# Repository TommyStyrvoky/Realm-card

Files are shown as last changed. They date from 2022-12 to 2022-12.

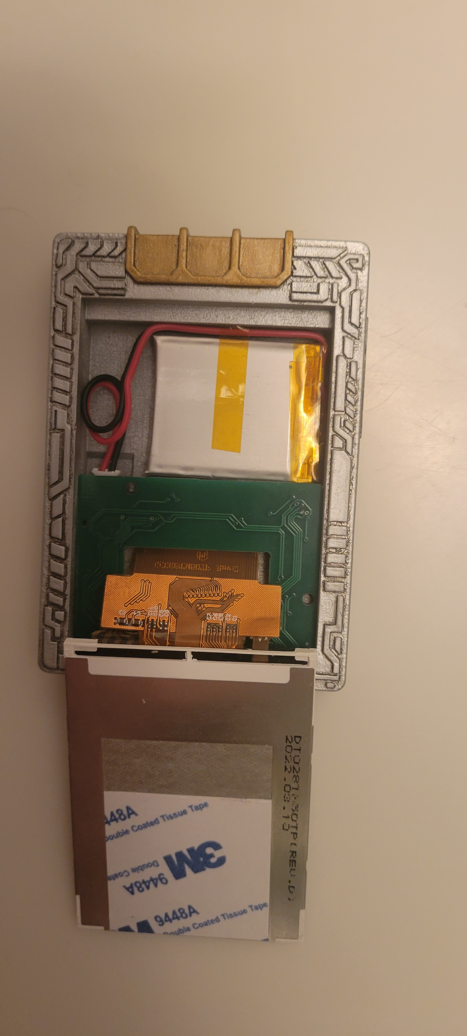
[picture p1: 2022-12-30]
assembly/Assembled.jpg

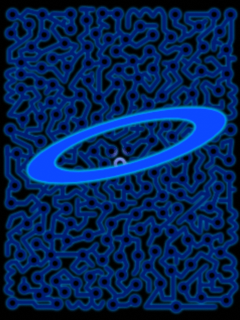
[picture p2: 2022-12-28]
animations/cosmic/1.bmp

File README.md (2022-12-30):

# Realm-card
A compact ESP32 TFT display/lipo charge circuit prop that loops through animations stored in folders on µSD card attached to PCB. Estimated battery life is ~2 hours. 

The length of the animations are limited by the resolution, as the maximum number of frames is limited by RAM space.
The animations are stored in directories under the root of the SD card, these folders are read from and 24 bit bmp images starting from and index of 1 to the maximum number of frames availible or maximum memory will be stored.

The addition of -L to the end of a directory name will make it loop without a randomized delay after completion of the animation.

See Adafruit BOM for additional components needed for the electronics aside from PCB, these were purchased through Adafruit's store, Digi-Key, and Mouser Electronics.
The ESP32 QT-PY will need to be soldered flush onto pads on the PCB, the throughholes are provided for alighment, this should be mounted flush, see assembly directory for photos. Polyamide (Kapton) tape will be used in some areas to insulate the PCB's connections on the back side, for this purpose 0.25" tape was used this is not listed on the BOM. Also not included in the BOM is some strong double sided tape, reccomend a thinner tape for adhesion of the pcb and LCD to the printed parts for removal in the future if needed to change the battery.

A couple revisions were made to the board than the photos that are attached, this removed some redundant components.

Included are KiCAD files for the PCB, there is a custom footprint that was created for the Adafruit QT-PY included. A step and STL file are included for the enclosure.

All production files are set up for manufacture using JLC PCB's service. BOM's and placement files are provided, missing parts may need to be substituted due to component shortages, CAD files and STL files included for printing using their SLA printers in their 8000 resin. Sanding was done after recieving the parts with some priming and sanding to reduce layer lines.
https://jlcpcb.com/

See Adafruit's ESP32 guide on setting up IDE for code upload to microcontroller.
https://learn.adafruit.com/adafruit-qt-py-esp32-pico

Adafruit libraries were used aside from the SPI library.

The enclosure was painted with Vallejo model air metallic, Mr surfacer, and Tamya paints using an airbrush and via a brush.

Primer:

mr surfacer 1000

Tamiya:

XF-1 

X-12 

panel line accent color black

Vallejo

71.062 Aluminum

71.072 Gunmetal

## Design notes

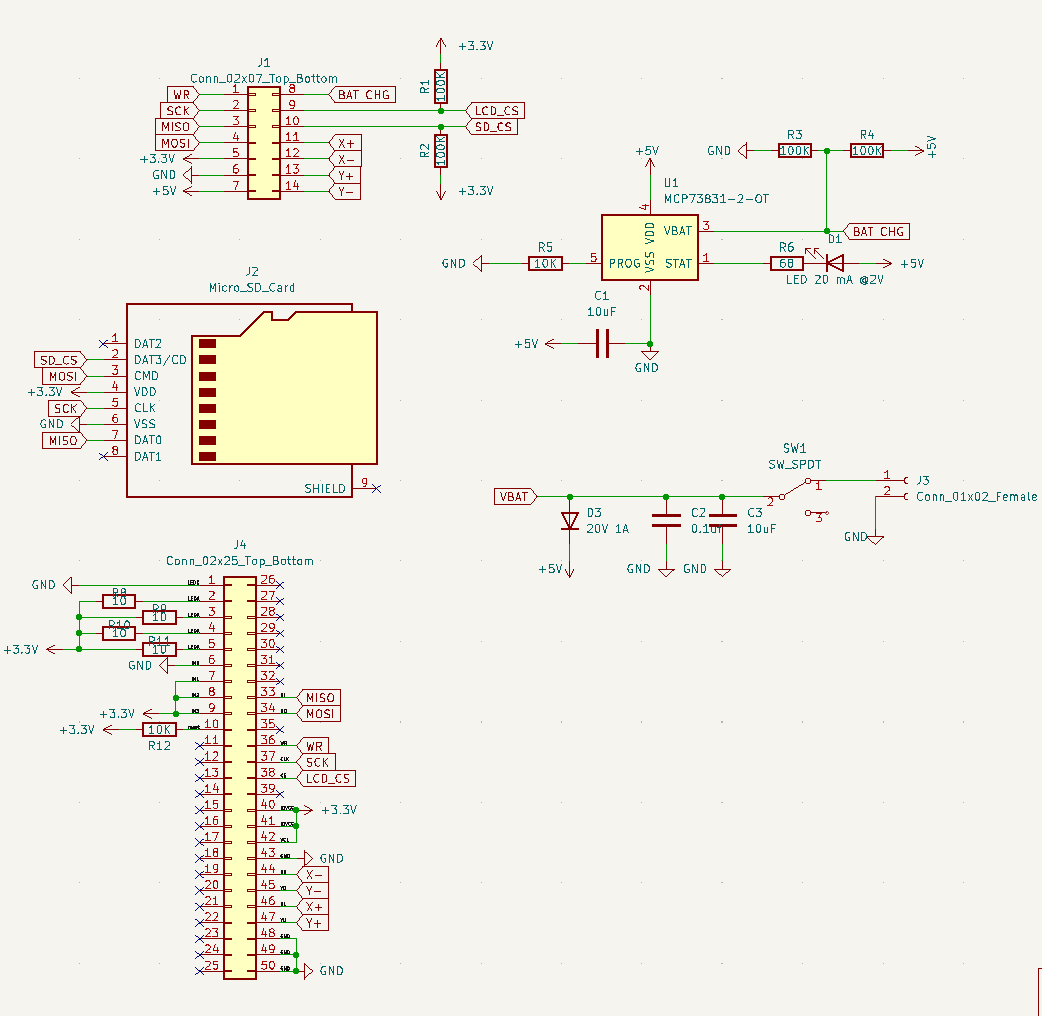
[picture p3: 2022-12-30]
electronics/Schematic.PNG

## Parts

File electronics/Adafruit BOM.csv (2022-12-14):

Adafruit Part# | Description
1774 | 2.8" TFT Display with Resistive Touchscreen
1578 | Lithium Ion Polymer Battery - 3.7v 500mAh
5395 | Adafruit QT Py ESP32 Pico - WiFi Dev Board with STEMMA QT - 8MB Flash 2MB PSRAM

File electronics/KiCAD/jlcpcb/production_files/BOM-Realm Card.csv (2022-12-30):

Comment | Designator | Footprint | LCSC
SW_SPDT | SW1 | SW_SPDT_CK-JS102011SAQN | C221660
LED 20 mA @2V | D1 | LED_0805_2012Metric | C2296
20V 1A | D3 | D_SOD-123 | C236132
Conn_01x02_Female | J3 | JST_PH_S2B-PH-SM4-TB_1x02-1MP_P2.00mm_Horizontal | C295747
Conn_02x25_Top_Bottom | J4 | Hirose_FH12-50S-0.5SH_1x50-1MP_P0.50mm_Horizontal | C375909
MCP73831-2-OT | U1 | SOT-23-5 | C424093
Micro_SD_Card | J2 | microSD_HC_Molex_104031-0811 | C585350
100K | R3 | R_0805_2012Metric
100K | R1 | R_0805_2012Metric
10 | R9 | R_0805_2012Metric
10uF | C1 | C_0805_2012Metric
10 | R10 | R_0805_2012Metric
10 | R8 | R_0805_2012Metric
10K | R5 | R_0805_2012Metric
Conn_02x07_Top_Bottom | J1 | Adafruit QT PY
100K | R2 | R_0805_2012Metric
0.1uf | C2 | C_0805_2012Metric
68 | R6 | R_0805_2012Metric
100K | R4 | R_0805_2012Metric
10 | R11 | R_0805_2012Metric
10K | R12 | R_0805_2012Metric
10uF | C3 | C_0805_2012Metric

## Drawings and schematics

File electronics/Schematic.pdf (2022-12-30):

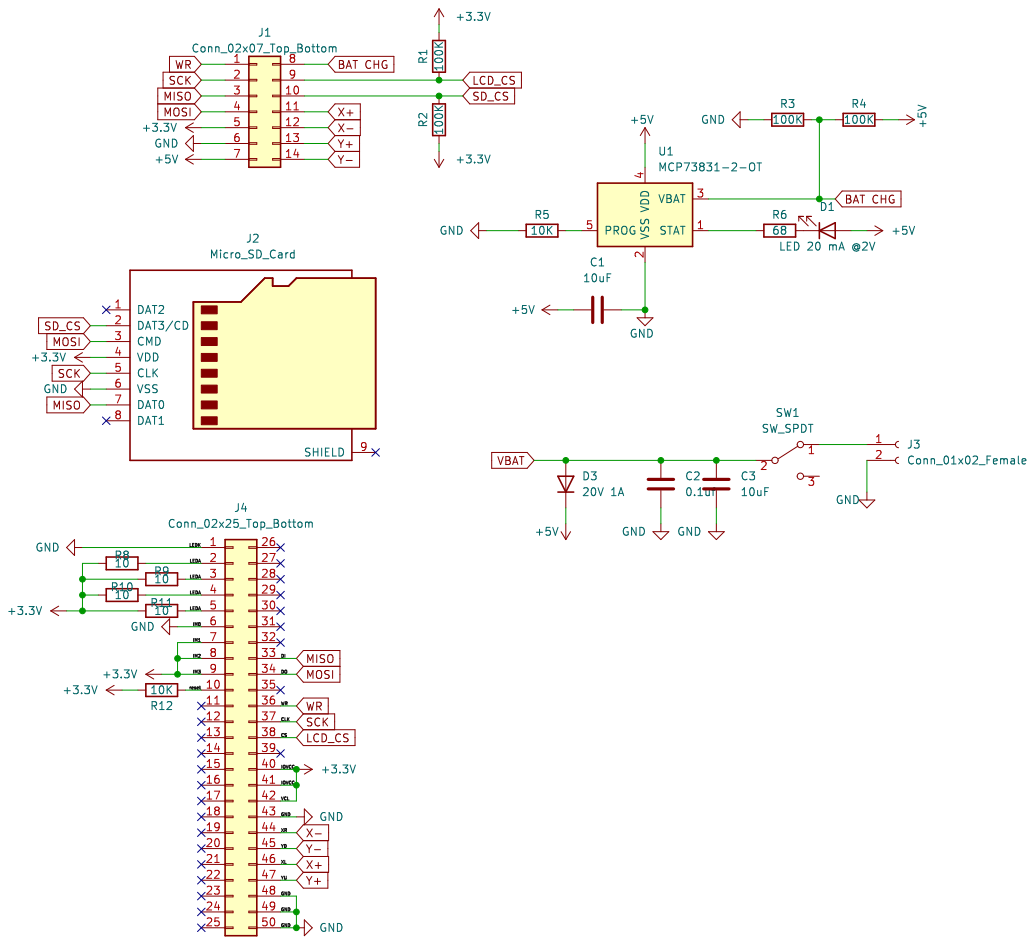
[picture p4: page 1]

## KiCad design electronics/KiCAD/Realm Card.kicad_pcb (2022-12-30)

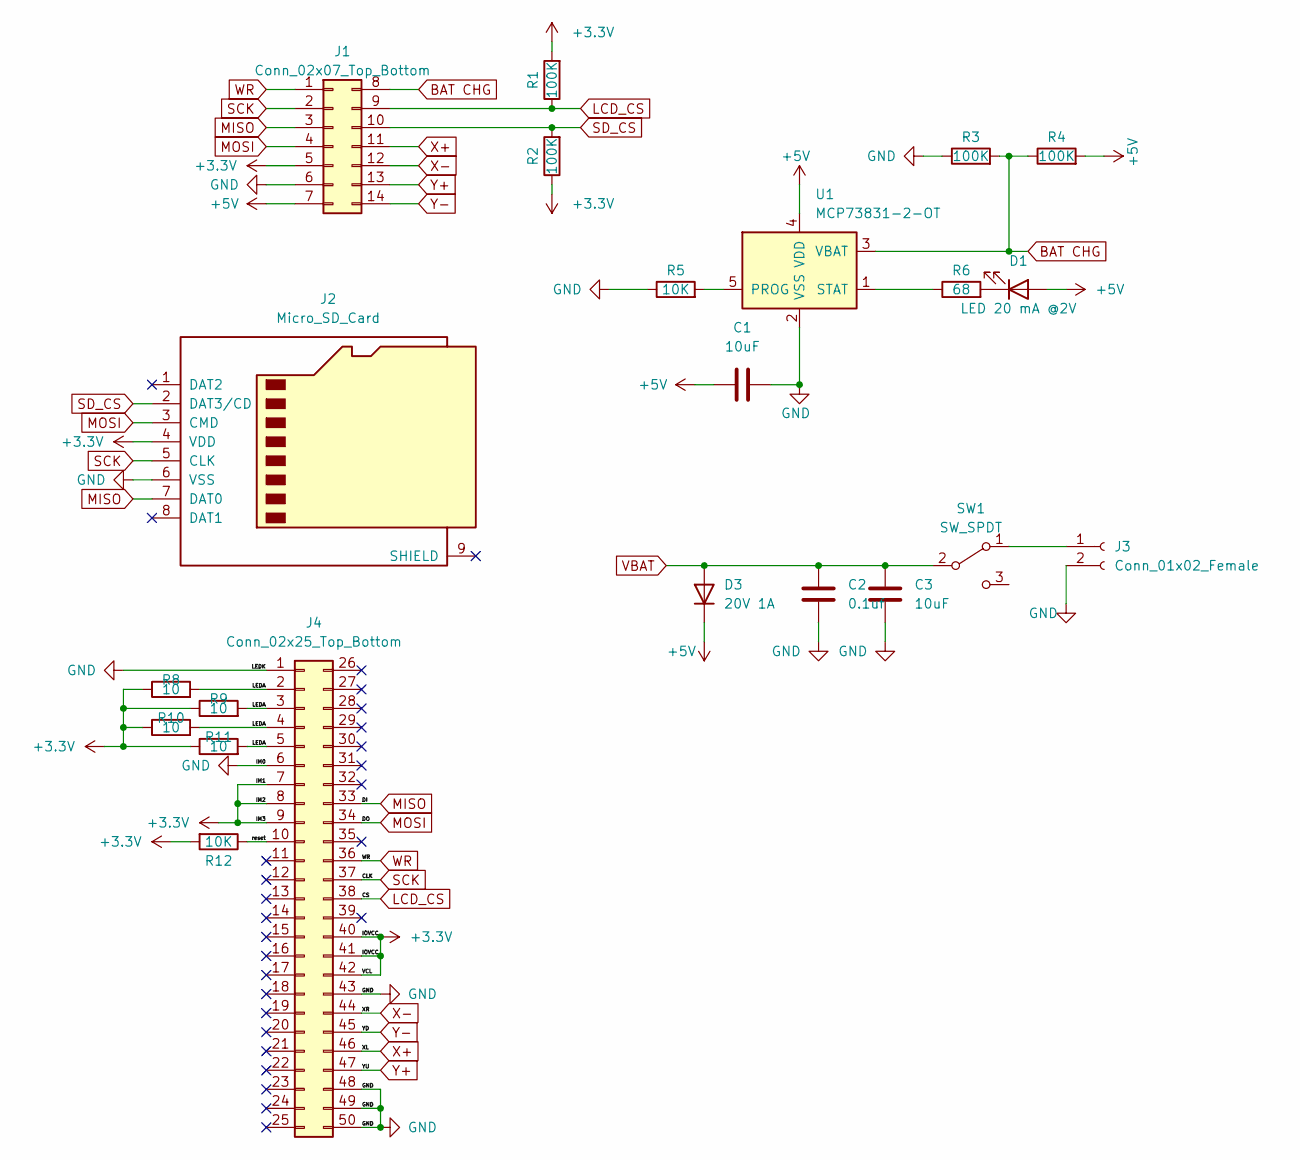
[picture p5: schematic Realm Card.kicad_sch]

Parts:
C1, C3: 10uF; C_0805_2012Metric
C2: 0.1uf; C_0805_2012Metric
D1: LED 20 mA @2V; LED_0805_2012Metric; LCSC C2296
D3: 20V 1A; D_SOD-123; LCSC C236132
J1: Conn_02x07_Top_Bottom; Adafruit QT PY
J2: Micro_SD_Card; microSD_HC_Molex_104031-0811; LCSC C585350
J3: Conn_01x02_Female; JST_PH_S2B-PH-SM4-TB_1x02-1MP_P2.00mm_Horizontal; LCSC C295747
J4: Conn_02x25_Top_Bottom; Hirose_FH12-50S-0.5SH_1x50-1MP_P0.50mm_Horizontal; LCSC C375909
R1, R2, R3, R4: 100K; R_0805_2012Metric
R5, R12: 10K; R_0805_2012Metric
R6: 68; R_0805_2012Metric
R8, R9, R10, R11: 10; R_0805_2012Metric
SW1: SW_SPDT; SW_SPDT_CK-JS102011SAQN; LCSC C221660
U1: MCP73831-2-OT; SOT-23-5; LCSC C424093

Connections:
+3.3V: J1.5, J2.4 (VDD), J4.7, J4.8, J4.9, J4.40, J4.41, J4.42, R1.2, R2.1, R8.1, R9.1, R10.1, R11.1, R12.2
+5V: C1.2, D1.2 (A), D3.1 (K), J1.7, R4.2, U1.4 (VDD)
/LEDA: J4.2, J4.3, J4.4, J4.5, R8.2, R9.2, R10.2, R11.2
/reset: J4.10, R12.1
BAT CHG: J1.8, R3.2, R4.1, U1.3 (VBAT)
GND: C1.1, C2.1, C3.1, J1.6, J2.6 (VSS), J3.2, J4.1, J4.6, J4.43, J4.48, J4.49, J4.50, R3.1, R5.1, U1.2 (VSS)
LCD_CS: J1.9, J4.38, R1.1
MISO: J1.3, J2.7 (DAT0), J4.33
MOSI: J1.4, J2.3 (CMD), J4.34
unnamed: D1.1 (K), R6.2
unnamed: J3.1, SW1.1 (A)
unnamed: R5.2, U1.5 (PROG)
unnamed: R6.1, U1.1 (STAT)
SCK: J1.2, J2.5 (CLK), J4.37
SD_CS: J1.10, J2.2 (DAT3/CD), R2.2
VBAT: C2.2, C3.2, D3.2 (A), SW1.2 (B)
WR: J1.1, J4.36
X+: J1.11, J4.46
X-: J1.12, J4.44
Y+: J1.13, J4.47
Y-: J1.14, J4.45

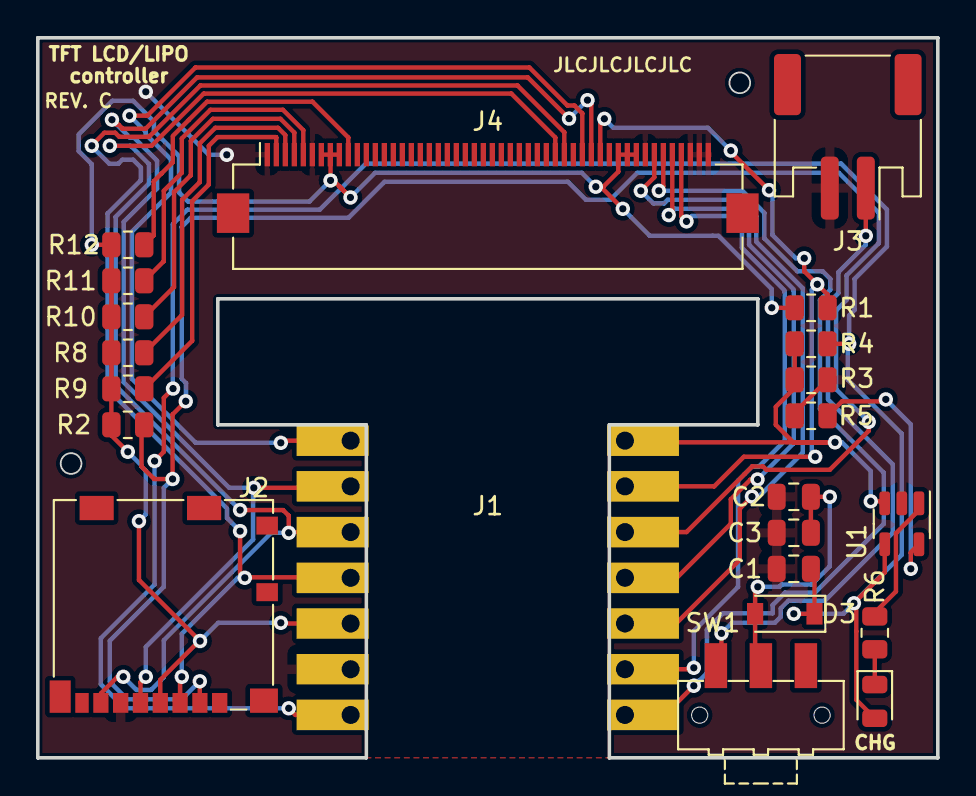
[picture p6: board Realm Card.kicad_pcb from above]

Board: 2 copper layers, 50.0 x 40.0 mm, 22 parts (0 on the bottom side), 21 nets.

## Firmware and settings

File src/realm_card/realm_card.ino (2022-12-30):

#include "SPI.h"
#include "SdFat.h"  // use Adafruit branch, sd card needs to be formatted to FAT16/FAT/32 with 32kb chunks
#include "Adafruit_ILI9341.h"
#include "Adafruit_ImageReader.h"
#include "Adafruit_GFX.h"
#include "TouchScreen.h"

#define loadRandom true  // selects a random animation on reboot to load

//pins
#define TFT_DC RX
#define TFT_CS SCL
#define SD_CS SDA
#define XM A0
#define XP A1
#define YM A3
#define YP A2
#define batteryStatus TX


#define touchscreenResistanceX 328  //measure this between x- & x+ with a multimeter to calibrate

//touchscreen remapping needs to be calibrated using the touchscreen demo
#define TS_MINY 190
#define TS_MINX 90
#define TS_MAXY 900
#define TS_MAXX 890

//GUI elements
#define triangleWidth 20
#define heightOffset 15
#define textSize 2

#define triangleOffset 30
#define lTriangleX 30
#define rTriangleX 210

// timing variables
#define baseFrameRate 24
float frameRate = baseFrameRate;
#define minDelay 1000
#define maxDelay 3000
#define touchCoolDown 2000
#define debounce 500
#define maxFramesToLoad 256  //anything beyond 12 frames of 240X320 overfills ram, this is just a placeholder for the maximum frames that could be loaded at a lower resolution
unsigned long framesLoaded;

// global variables
uint x, y;
unsigned long currentFrame, lastFrameDraw, lastTouchEvent, lastpress, delayTime = random(minDelay, maxDelay), lastDelay;
unsigned long currentDirectory = 1, selectedDirectory = 1;  //directory 0 = system
#define strBufferSize 64                                    //max directory name length
#define folderListCT 256                                    // max number of directories
char fileName[strBufferSize];
char folderList[folderListCT][strBufferSize];
uint folderCount;
bool uIActiveFlag, debounceFlag, delayFlag, redrawFlag, loopAnimation;
char extension[] = ".bmp";
#define SD_MHZ 25

// classes
SdFat SD;
SdFile root;
SdFile directory;
TouchScreen ts = TouchScreen(XP, YP, XM, YM, touchscreenResistanceX);
Adafruit_ILI9341 tft = Adafruit_ILI9341(TFT_CS, TFT_DC);
Adafruit_ImageReader reader(SD);
Adafruit_Image img[maxFramesToLoad];


int32_t width, height;

void setup() {  //first loop
  Serial.begin(115200);
  analogReadResolution(10);  //touch library requires 10 bit ADC
  pinMode(batteryStatus, INPUT);
  tft.begin();
  if (!SD.begin(SD_CS, SD_SCK_MHZ(SD_MHZ))) {  //check sd card
    tft.fillScreen(0);
    tft.setTextColor(ILI9341_RED);
    tft.setTextSize(textSize);
    drawCenteredText("SD Card", 120, 160 - 12);
    drawCenteredText("not detected", 120, 160 + 12);
    while (true) {}  //do nothing
  }
  tft.fillScreen(0);  //load screen here
  tft.setTextColor(ILI9341_WHITE);
  tft.setTextSize(textSize);
  drawCenteredText("Reading", 120, 160 - 12);
  drawCenteredText("card.", 120, 160 + 12);
  root.open("/");
  SD.vwd()->rewind();
  while (directory.openNext(&root, O_RDONLY)) {  //read all of the directories on the sd card and store their names to memory
    if (directory.isDir()) {
      directory.getName(folderList[folderCount], strBufferSize);
      folderCount++;
    }
    directory.close();
  }
  char folderCountChar[10];
  //folderCount--;
  ltoa(folderCount-1, folderCountChar, 10);
  tft.fillScreen(0);  //end load screen
  tft.setTextColor(ILI9341_WHITE);
  tft.setTextSize(textSize);
  drawCenteredText("Found", 120, 160 - 24);
  drawCenteredText(folderCountChar, 120, 160);
  drawCenteredText("animations.", 120, 160 + 24);
  currentFrame = 0;

  if (loadRandom) {
    currentDirectory = random(1, folderCount);
  } else {
    currentDirectory = 1;
  }

  delay(1000);
  loadFrames();
}

void loop() {                 //main
  TSPoint p = ts.getPoint();  //touchscreen events
  if (p.z > ts.pressureThreshhold) {
    y = map(p.x, TS_MAXX,TS_MINX, tft.height(), 0);//flip x and y because of orientation of display
    x = map(p.y, TS_MINY, TS_MAXY, tft.width(), 0);
    if (!uIActiveFlag) {  //draw ui after first event detectd
      redrawFlag = true;
    }
    uIActiveFlag = true;
    lastTouchEvent = millis();
  }

  if ((millis() - lastTouchEvent >= touchCoolDown) && uIActiveFlag) {  //hide UI if not active and load next frame set if changed
    uIActiveFlag = false;
    if (currentDirectory != selectedDirectory) {  //only load new frames if directory changed
      currentDirectory = selectedDirectory;
      currentFrame = 0;
      loadFrames();
    } else {
      selectedDirectory = currentDirectory;
    }
  }

  if (millis() - lastpress >= debounce) {  //set debounce flag false after elapsed
    debounceFlag = false;
  }

  if (millis() - lastFrameDraw >= (1 / frameRate) * 1000) {  //draw frame from ram every frame interval and update display
    lastFrameDraw = millis();
    if (!uIActiveFlag) {  //fill with black before rendering samller images than display size
      frameRate = baseFrameRate;
      playFrame();
    }

    if (uIActiveFlag) {               //button events
      if (!debounceFlag) {            //debounce inputs
        if ((x > 0) && (x < (50))) {  //left button pressed
          if ((y > 0) && (y <= 50)) {
            if (p.z > ts.pressureThreshhold) {
              selectedDirectory--;
              if (selectedDirectory < 1) {
                selectedDirectory = folderCount - 1;
              }
              debounceFlag = true;
              redrawFlag = true;
              lastpress = millis();
            }
          }
        }
        if ((x > 190) && (x < (240))) {  //right button pressed
          if ((y > 0) && (y <= 50)) {
            if (p.z > ts.pressureThreshhold) {
              selectedDirectory++;
              if (selectedDirectory > folderCount - 1) {
                selectedDirectory = 1;
              }
              debounceFlag = true;
              redrawFlag = true;
              lastpress = millis();
            }
          }
        }
      }
    }

    if (redrawFlag) {  //draw ui on demand
      redrawFlag = false;
      tft.fillRect(0, 0, tft.width(), heightOffset + triangleOffset, 0);
      //draw right and left buttons
      tft.fillTriangle(lTriangleX, heightOffset, lTriangleX, heightOffset + triangleWidth, lTriangleX - triangleWidth, heightOffset + triangleWidth / 2, ILI9341_WHITE);
      tft.fillTriangle(rTriangleX, heightOffset, rTriangleX, heightOffset + triangleWidth, rTriangleX + triangleWidth, heightOffset + triangleWidth / 2, ILI9341_WHITE);

      //draw text
      tft.setTextColor(ILI9341_WHITE);
      tft.setTextSize(textSize);
      drawCenteredText(folderList[selectedDirectory], 120, heightOffset + triangleWidth / 2);

      //TODO calculate battery voltage
      //TODO draw battery %
    }
  }
}

void drawCenteredText(char* text, int px, int py) {
  int16_t x1, y1;
  uint16_t w, h;
  tft.getTextBounds(text, 0, 0, &x1, &y1, &w, &h);
  tft.setCursor((px - w / 2), (py - h / 2));
  tft.println(text);
}

void loadFrames() {  //loads frames into memory from sdcard //TODO fix some bug here with going from high to low frame counts results in failure to load more than one frame
  framesLoaded = 0;
  char path[strBufferSize];
  ImageReturnCode stat;
  char buffer[strBufferSize + strBufferSize + 10 + 4];
  char frameChar[10];

  strcpy(path, folderList[currentDirectory]);
  strcat(path, "/");

  tft.fillScreen(0);
  Serial.print("Loading: ");
  Serial.print(folderList[currentDirectory]);
  Serial.println("/");
  while (true) {  //keep loading frames if they exist or until no more memory can be allocated
    ltoa(framesLoaded + 1, frameChar, 10);
    strcpy(buffer, path);

    strcat(buffer, frameChar);
    strcat(buffer, extension);
    Serial.print("Frame: ");
    Serial.println(frameChar);
    reader.bmpDimensions(buffer, &width, &height);
    stat = reader.loadBMP(buffer, img[framesLoaded]);
    reader.printStatus(stat);
    if (stat != 0) {  //anything other than success
      framesLoaded--;
      break;
    }
    tft.fillScreen(0);
    tft.setTextSize(textSize);
    drawCenteredText(folderList[currentDirectory], 120, 160 - 24);
    drawCenteredText("loaded frame", 120, 160);
    drawCenteredText("to RAM:", 120, 160+ 24);
    drawCenteredText(frameChar, 120, 160 + 48);
    framesLoaded++;
  }
  if (framesLoaded >= maxFramesToLoad) {  //prevent overflow
    framesLoaded = maxFramesToLoad;
  }
  tft.fillScreen(0);
  drawCenteredText("Done", 120, 160);
  delay(250);
  tft.fillScreen(0);

  if (folderList[currentDirectory][strlen(folderList[currentDirectory]) - 2] == '-' && folderList[currentDirectory][strlen(folderList[currentDirectory]) - 1] == 'L') {  // if the directory contains -L afterwards it will ignore the delay
    loopAnimation = true;
  } else {
    loopAnimation = false;
  }
}

void playFrame() {                                                                                                                                     //indexes through frame objects
  img[currentFrame].draw(tft, constrain(tft.width() / 2 - (width / 2), 0, tft.width()), constrain(tft.height() / 2 - (height / 2), 0, tft.height()));  //draw in center of display
  if (currentFrame >= framesLoaded && !loopAnimation && !delayFlag) {
    delayFlag = true;
    delayTime = random(minDelay, maxDelay);
    lastDelay = millis();
  }
  if (millis() - lastDelay >= delayTime && delayFlag) {
    delayFlag = false;
  }
  if (!delayFlag) {  //prevents advance to next frame if delay is in place at end of sequence
    currentFrame++;
    if (currentFrame > framesLoaded) {
      currentFrame = 0;
    }
  }
}

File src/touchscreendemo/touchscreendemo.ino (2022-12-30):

// modified version of Adafruit's Touchscreen example to use for calibration of the max and min values
//use a stylus or other tool to measure the min and max values over serial for the x and y values to remap the touchscreen to the display
#define touchscreenResistanceX 328  //measure this between x- & x+ with a multimeter to calibrate


// Touch screen library with X Y and Z (pressure) readings as well
// as oversampling to avoid 'bouncing'
// This demo code returns raw readings, public domain

#include <stdint.h>
#include "TouchScreen.h"

#define YM A0
#define YP A1
#define XM A3
#define XP A2

// For better pressure precision, we need to know the resistance
// between X+ and X- Use any multimeter to read it
// For the one we're using, its 300 ohms across the X plate
TouchScreen ts = TouchScreen(XP, YP, XM, YM, touchscreenResistanceX);

void setup(void) {
    analogReadResolution(10);
  Serial.begin(9600);
}

void loop(void) {
  // a point object holds x y and z coordinates
  TSPoint p = ts.getPoint();

  // we have some minimum pressure we consider 'valid'
  // pressure of 0 means no pressing!
  if (p.z > ts.pressureThreshhold) {
     Serial.print("X = "); Serial.print(p.x);
     Serial.print("\tY = "); Serial.print(p.y);
     Serial.print("\tPressure = "); Serial.println(p.z);
  }
}

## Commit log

2022-12-14 Committed files
    [BOM-Realm Card.csv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]
2022-12-14 Added BOM
    [Adafruit BOM.csv]
2022-12-14 Moved BOM
    [Adafruit BOM.csv]
2022-12-14 Create PCB assembly.PNG
2022-12-20 updated board
    [BOM-Realm Card.csv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]
2022-12-21 revised code
    [Realm Card.kicad_sch]
2022-12-28 reworked code
    [Realm Card.kicad_pcb, Realm Card.kicad_sch]
2022-12-30 Added documentation
    [BOM-Realm Card.csv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]
2022-12-30 revised schematic
